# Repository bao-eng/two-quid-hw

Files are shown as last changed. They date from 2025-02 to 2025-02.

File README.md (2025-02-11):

# two-quid-hw
Miniature nRF54L-based board with IMU/RGB LED/button/buzzer/2032 battery

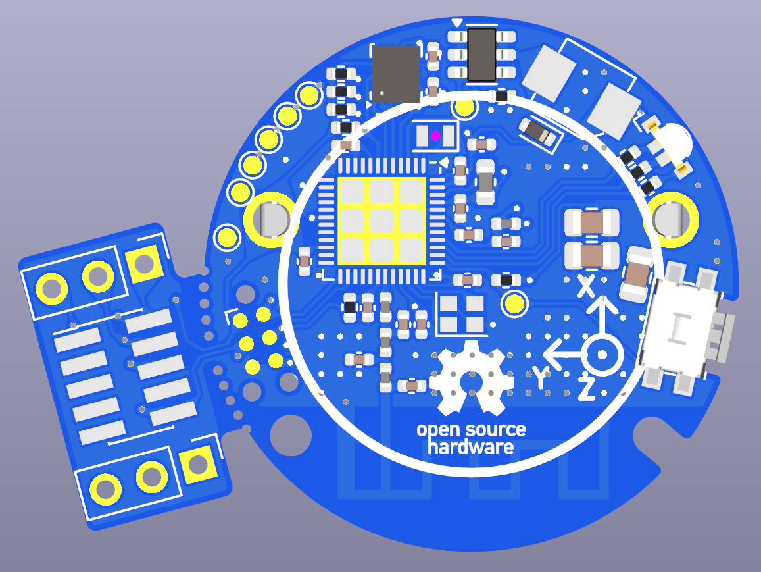
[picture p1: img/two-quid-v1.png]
two-quid


## Features
- Nordic nRF54L15 wireless SoC
- ST LSM6DSL 6DoF IMU
- RGB LED indicator
- Push-button
- 4kHz buzzer
- Powered by replaceable 2032 coin cell battery
- £2 coin-sized PCB(D=28.4mm)
- ~6.5mm overall PCBA height
- Sane 0402 components
- Breakaway piece with debugging connectors: \
    10-pin [Cortex-Debug](https://developer.arm.com/documentation/101416/0100/Hardware-Description/Target-Interfaces/Cortex-Debug--10-pin-) (1.27mm pitch) connector for debugging using nRF54L15-DK+[IDC cable](https://www.adafruit.com/product/1675) or J-Link+[ARM-JTAG-20-10 cable](https://www.olimex.com/Products/ARM/JTAG/ARM-JTAG-20-10/) \
    2x3-pin (2.54mm pitch) connectors for jumper wires

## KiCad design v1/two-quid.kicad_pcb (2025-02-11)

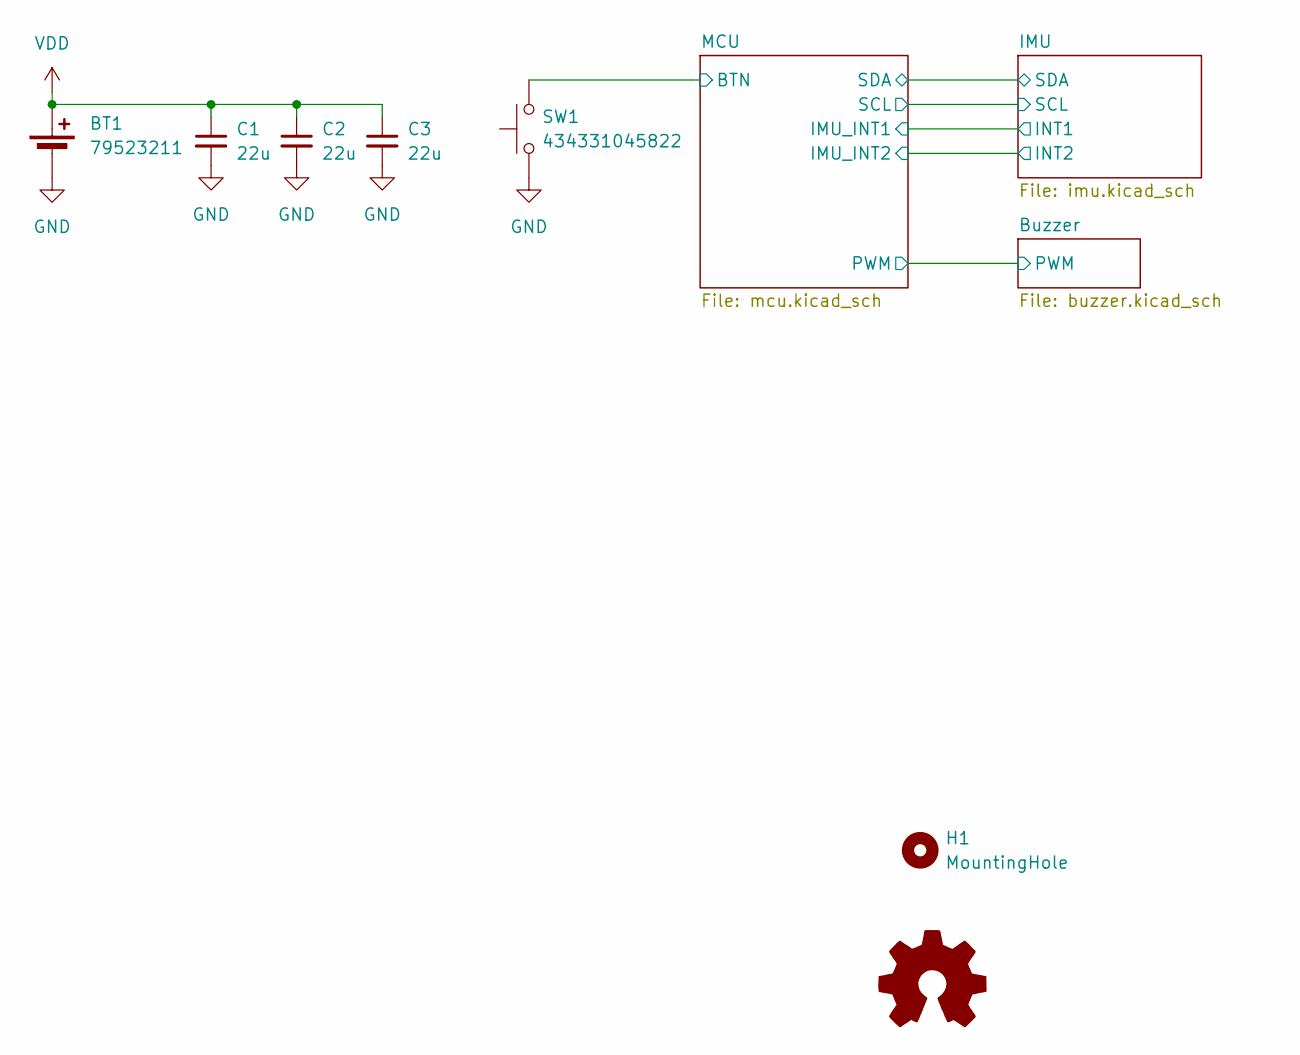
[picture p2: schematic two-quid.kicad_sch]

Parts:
BT1: 79523211; BatteryHolder_WE_79523211_1x2016,2020,2025,2032
C1, C2, C3: 22u; C_0805_2012Metric; MPN 885012107005
H1: MountingHole; MountingHole_2.2mm_M2
SW1: 434331045822
SYM1: Logo_Open_Hardware_Small; OSHW-Logo_5.7x6mm_SilkScreen

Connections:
/MCU/BTN: SW1.2; also elsewhere on the board
GND: BT1.2 (-), C1.2, C2.2, C3.2, SW1.1; also elsewhere on the board
VDD: BT1.1 (+), C1.1, C2.1, C3.1; also elsewhere on the board

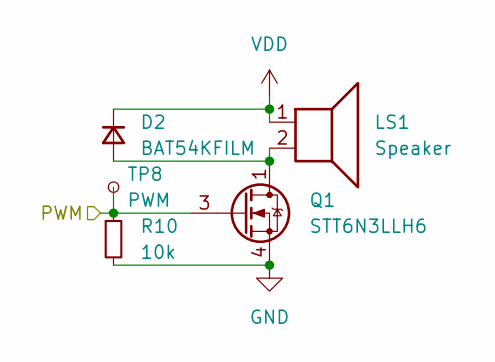
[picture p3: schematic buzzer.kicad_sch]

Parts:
D2: BAT54KFILM; D_SOD-523
LS1: Speaker; OWMB-404020SA-40-17
Q1: STT6N3LLH6; SOT-23-6
R10: 10k; R_0402_1005Metric; MPN 560112110020
TP8: PWM; TestPoint_Pad_D1.0mm

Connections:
/Buzzer/PWM: Q1.3 (G), R10.1, TP8.1; also elsewhere on the board
GND: Q1.4 (S), R10.2; also elsewhere on the board
unnamed: D2.2 (A), LS1.2, Q1.1 (D), Q1.2 (D), Q1.5 (D), Q1.6 (D)
VDD: D2.1 (K), LS1.1; also elsewhere on the board

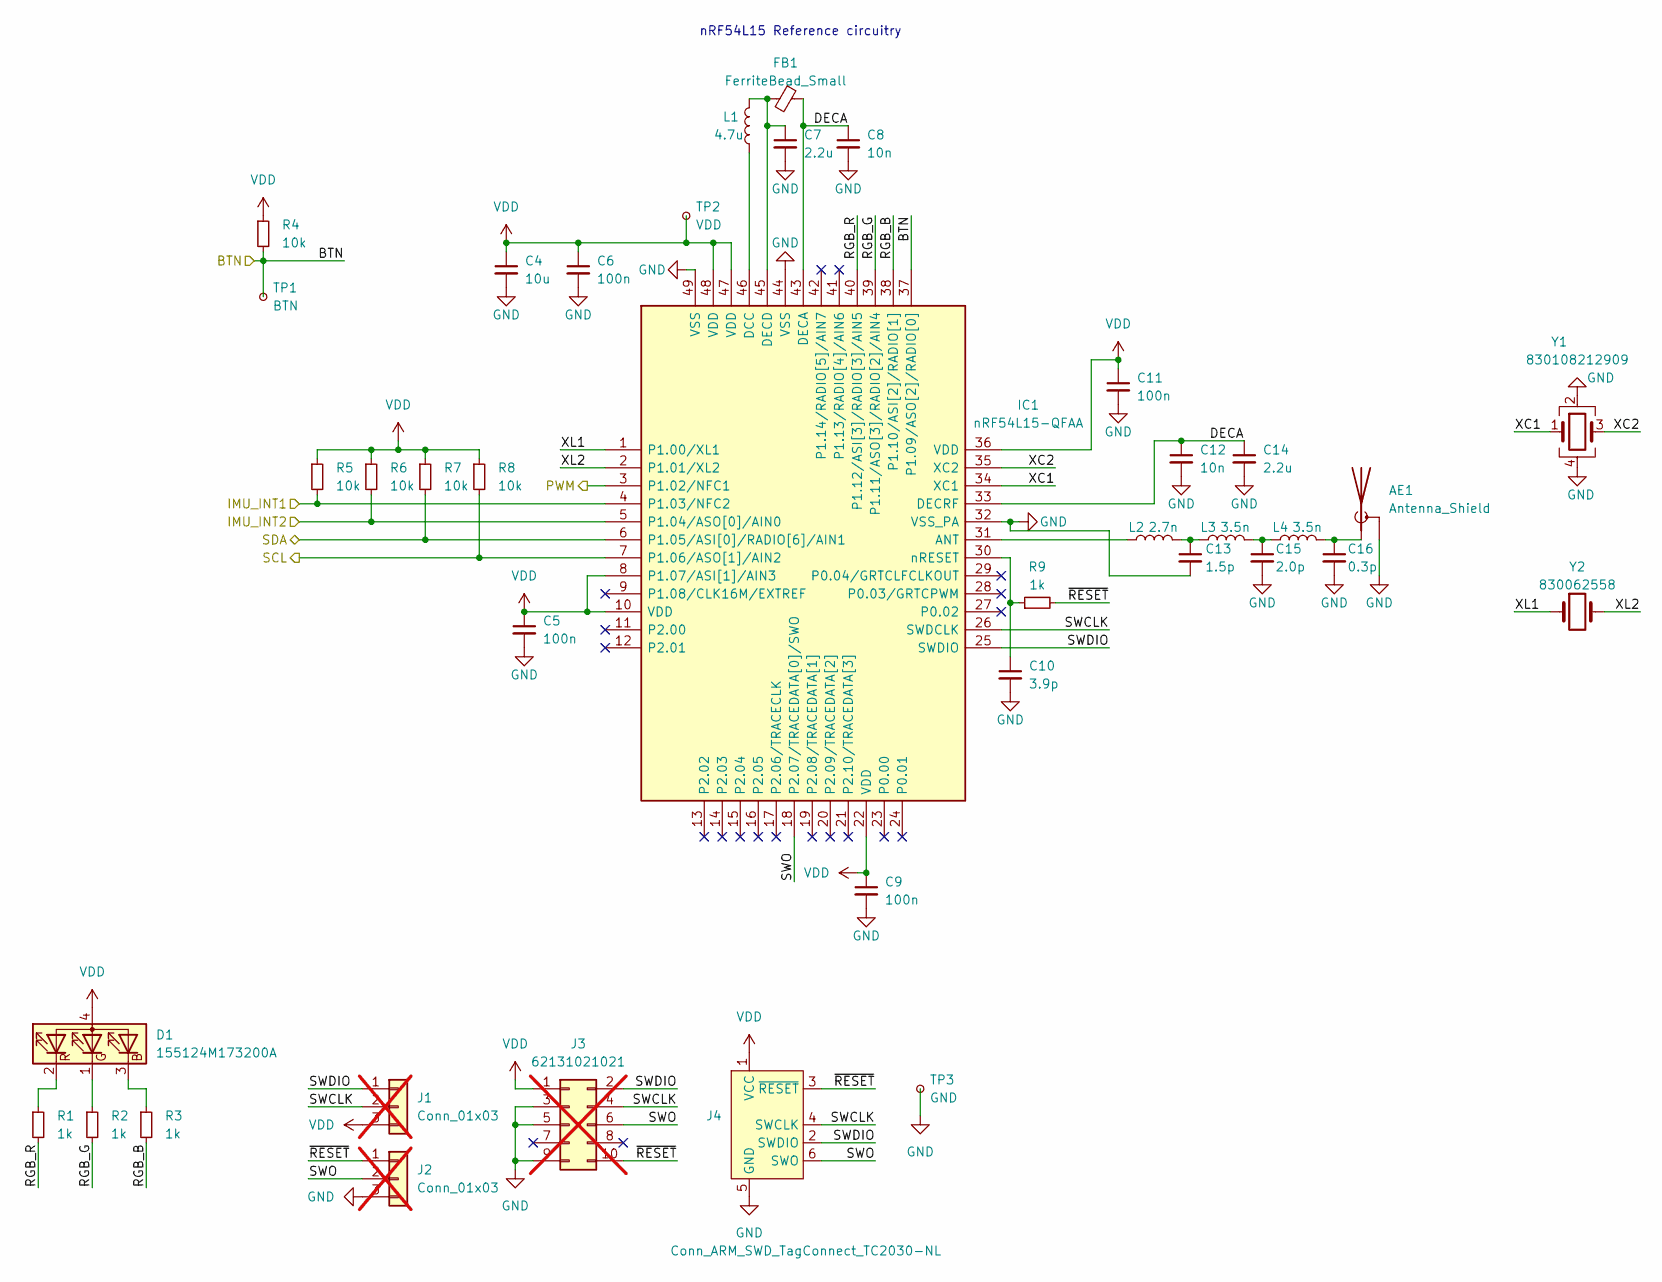
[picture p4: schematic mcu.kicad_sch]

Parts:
AE1: Antenna_Shield; Texas_SWRA117D_2.4GHz_Left
C4: 10u; C_0402_1005Metric; MPN 885012105020
C5, C6, C9, C11: 100n; C_0402_1005Metric; MPN 885012205018
C7, C14: 2.2u; C_0402_1005Metric; MPN 885012105013
C8, C12: 10n; C_0402_1005Metric; MPN 885012205012
C10: 3.9p; C_0402_1005Metric; MPN 885012205018
C13: 1.5p; C_0402_1005Metric; MPN CBR04C159A3GAC/GJM1555C1H1R5WB01D
C15: 2.0p; C_0402_1005Metric; MPN GJM1555C1H2R0WB01D
C16: 0.3p; C_0402_1005Metric; MPN GJM1555C1HR30BB01D
D1: 155124M173200A
FB1: FerriteBead_Small; L_0402_1005Metric; MPN 74279271
IC1: nRF54L15-QFAA; QFN-48-1EP_6x6mm_P0.4mm_EP4.66x4.66mm; Manufacturer_Part_Number nRF54L15-QFAA
J1, J2: Conn_01x03; PinHeader_1x03_P2.54mm_Vertical; not fitted
J3: 62131021021; PinHeader_2x05_P1.27mm_Vertical_SMD; not fitted
J4: Conn_ARM_SWD_TagConnect_TC2030-NL; Tag-Connect_TC2030-IDC-NL_2x03_P1.27mm_Vertical
L1: 4.7u; L_0603_1608Metric; MPN MLZ1608M4R7WT000
L2: 2.7n; L_0402_1005Metric; MPN 744765027A
L3: 3.5n; L_0402_1005Metric; MPN LQG15WH3N5B02D
L4: 3.5n; L_0402_1005Metric; MPN LQG15WH3N5B02D/MHQ1005075HA3N5BTD25
R1, R2, R3, R9: 1k; R_0402_1005Metric; MPN 560112110012
R4, R5, R6, R7, R8: 10k; R_0402_1005Metric; MPN 560112110020
TP1: BTN; TestPoint_Pad_D1.0mm
TP2: VDD; TestPoint_Pad_D1.0mm
TP3: GND; TestPoint_Pad_D1.0mm
Y1: 830108212909; Crystal_SMD_2016-4Pin_2.0x1.6mm
Y2: 830062558; Crystal_SMD_2012-2Pin_2.0x1.2mm

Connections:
/Buzzer/PWM: IC1.3 (P1.02/NFC1); also elsewhere on the board
/IMU/INT1: IC1.4 (P1.03/NFC2), R5.2; also elsewhere on the board
/IMU/INT2: IC1.5 (P1.04/ASO[0]/AIN0), R6.2; also elsewhere on the board
/IMU/SCL: IC1.7 (P1.06/ASO[1]/AIN2), R8.2; also elsewhere on the board
/IMU/SDA: IC1.6 (P1.05/ASI[0]/RADIO[6]/AIN1), R7.2; also elsewhere on the board
/MCU/BTN: IC1.37 (P1.09/ASO[2]/RADIO[0]), R4.2, TP1.1; also elsewhere on the board
/MCU/DECA: C8.1, C12.1, C14.1, FB1.1, IC1.33 (DECRF), IC1.43 (DECA)
/MCU/RGB_B: IC1.38 (P1.10/ASI[2]/RADIO[1]), R3.2
/MCU/RGB_G: IC1.39 (P1.11/ASO[3]/RADIO[2]/AIN4), R2.2
/MCU/RGB_R: IC1.40 (P1.12/ASI[3]/RADIO[3]/AIN5), R1.2
/MCU/SWCLK: IC1.26 (SWDCLK), J1.2, J3.4, J4.4 (SWCLK)
/MCU/SWDIO: IC1.25 (SWDIO), J1.1, J3.2, J4.2 (SWDIO)
/MCU/SWO: IC1.18 (P2.07/TRACEDATA[0]/SWO), J2.2, J3.6, J4.6 (SWO)
/MCU/XC1: IC1.34 (XC1), Y1.1
/MCU/XC2: IC1.35 (XC2), Y1.3
/MCU/XL1: IC1.1 (P1.00/XL1), Y2.1
/MCU/XL2: IC1.2 (P1.01/XL2), Y2.2
/MCU/~RESET: J2.1, J3.10, J4.3 (~RESET), R9.2
GND: AE1.2 (Shield), C4.2, C5.2, C6.2, C7.2, C8.2, C9.2, C10.2, C11.2, C12.2, C13.2, C14.2, C15.2, C16.2, IC1.32 (VSS_PA), IC1.44 (VSS), IC1.49 (VSS), J2.3, J3.3, J3.5, J3.9, J4.5 (GND), TP3.1, Y1.2, Y1.4; also elsewhere on the board
unnamed: AE1.1 (A), C16.1, L4.2
unnamed: C13.1, L2.2, L3.1
unnamed: C15.1, L3.2, L4.1
unnamed: D1.3 (BK), R3.1
unnamed: D1.1 (GK), R2.1
unnamed: D1.2 (RK), R1.1
unnamed: IC1.31 (ANT), L2.1
unnamed: IC1.46 (DCC), L1.1
unnamed: C7.1, FB1.2, IC1.45 (DECD), L1.2
unnamed: C10.1, IC1.30 (nRESET), R9.1
VDD: C4.1, C5.1, C6.1, C9.1, C11.1, D1.4 (A), IC1.8 (P1.07/ASI[1]/AIN3), IC1.10 (VDD), IC1.22 (VDD), IC1.36 (VDD), IC1.47 (VDD), IC1.48 (VDD), J1.3, J3.1, J4.1 (VCC), R4.1, R5.1, R6.1, R7.1, R8.1, TP2.1; also elsewhere on the board

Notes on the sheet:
nRF54L15 Reference circuitry

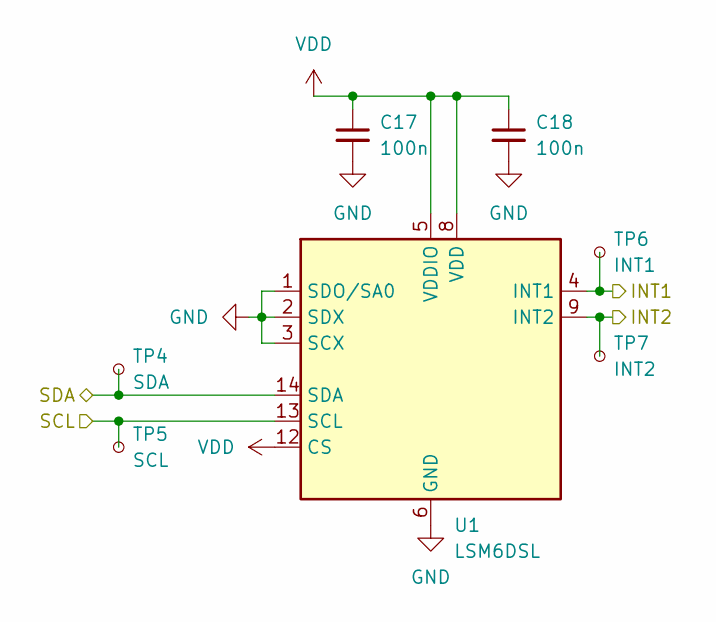
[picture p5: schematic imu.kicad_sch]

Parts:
C17, C18: 100n; C_0402_1005Metric; MPN 885012205018
TP4: SDA; TestPoint_Pad_D1.0mm
TP5: SCL; TestPoint_Pad_D1.0mm
TP6: INT1; TestPoint_Pad_D1.0mm
TP7: INT2; TestPoint_Pad_D1.0mm
U1: LSM6DSL; LGA-14_3x2.5mm_P0.5mm_LayoutBorder3x4y

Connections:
/IMU/INT1: TP6.1, U1.4 (INT1); also elsewhere on the board
/IMU/INT2: TP7.1, U1.9 (INT2); also elsewhere on the board
/IMU/SCL: TP5.1, U1.13 (SCL); also elsewhere on the board
/IMU/SDA: TP4.1, U1.14 (SDA); also elsewhere on the board
GND: C17.2, C18.2, U1.1 (SDO/SA0), U1.2 (SDX), U1.3 (SCX), U1.6 (GND), U1.7 (GND); also elsewhere on the board
VDD: C17.1, C18.1, U1.5 (VDDIO), U1.8 (VDD), U1.12 (CS); also elsewhere on the board

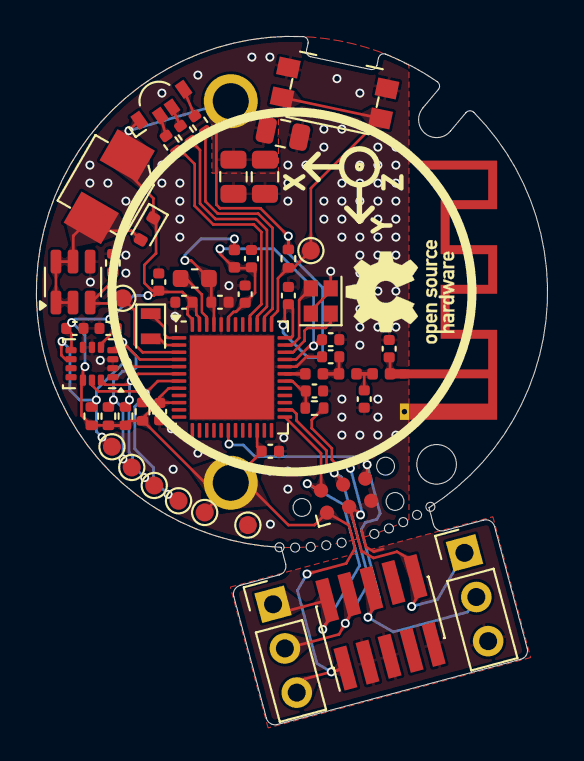
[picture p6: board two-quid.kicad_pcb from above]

Board: 2 copper layers, 28.4 x 38.2 mm, 58 parts (1 on the bottom side), 31 nets.
